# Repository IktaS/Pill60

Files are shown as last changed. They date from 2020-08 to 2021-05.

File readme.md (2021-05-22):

This is Pill 60, it offers various bottom row layout, a stepped caps, an OLED screen, and two rotary encoder, and uses Kailh Hotswap Socket, and underglow RGB LED.

layout is [this](http://www.keyboard-layout-editor.com/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)

This 60% keyboard that uses BluePill or STM32F103C8T6.This is my first board, Any feedback is appreciated. Contact me on Discord Ikta#8871.

## Firmware
Firmware is currently waiting for merge to QMK Firmware Repository, but you can still access it from my [fork](https://github.com/IktaS/qmk_firmware/tree/pill60/keyboards/handwired/pill60)

## Update
Modified the pinout diagram so that it doesn't crash with Black Pill or STM32F4xxx line of board, the pinout obviously will be different, but because all uses the a valid pin even with Black Pill / Blue Pill configuration, pin matrix diagram can be modified in firmware level.

## Caution
You might need to use a jumper for a more reliable connector in the caps/control key. I guess the pad is a bit too small for it to keep holding on with constant pressure of being pressed hard.

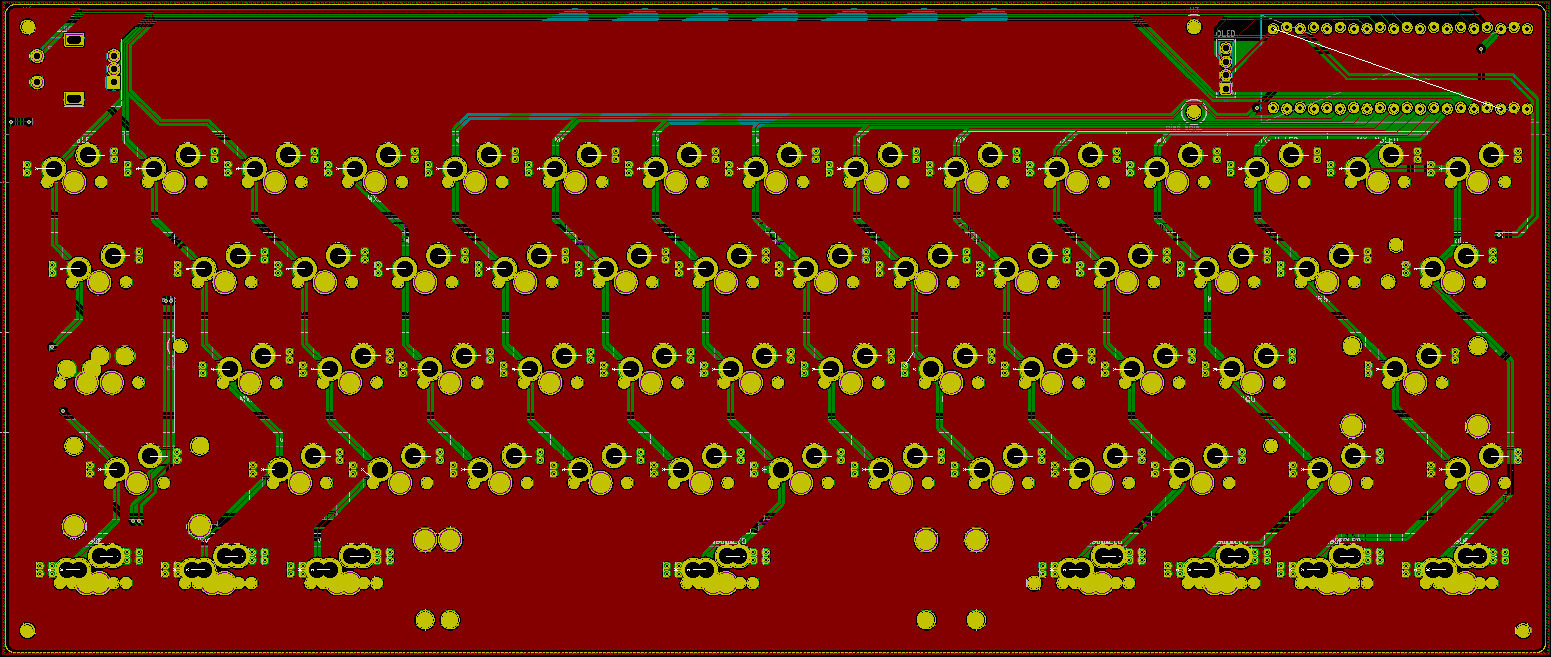
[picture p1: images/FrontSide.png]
Front Side view

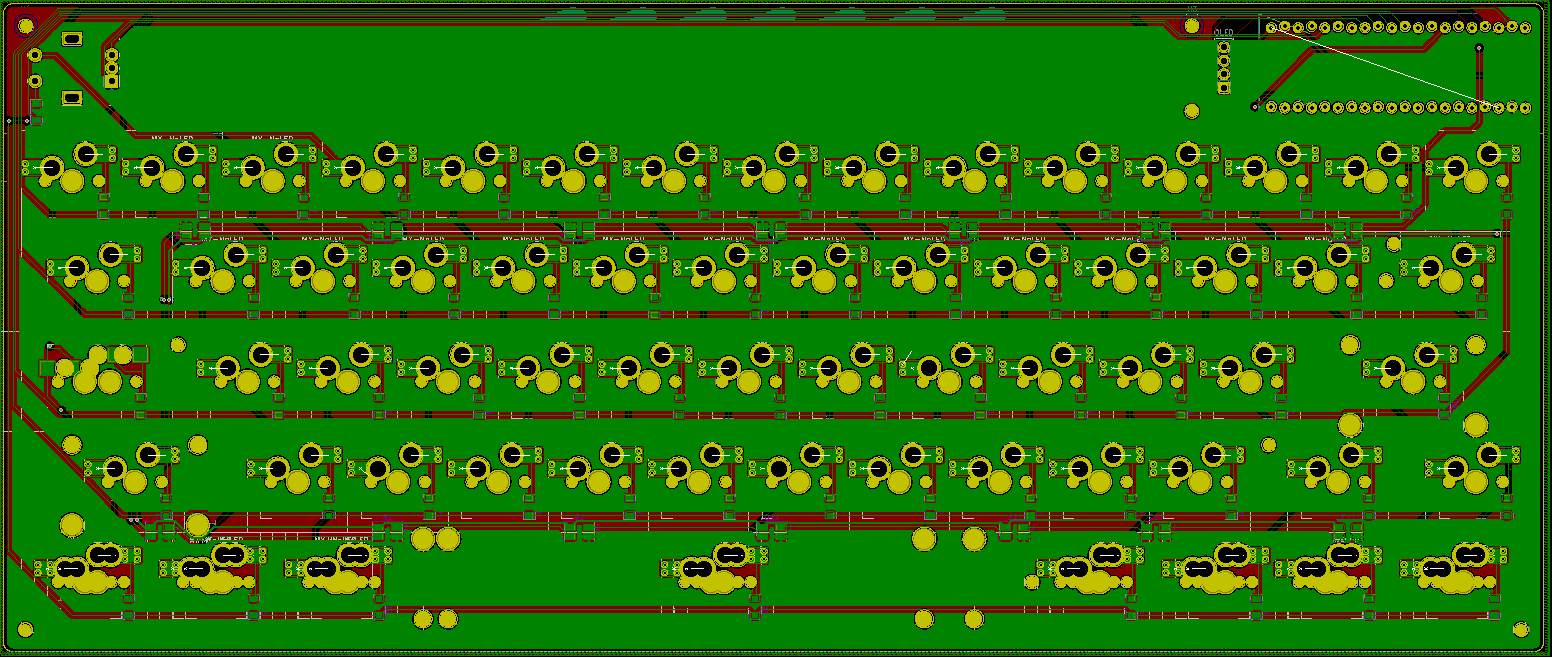
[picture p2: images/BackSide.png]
Back Side view

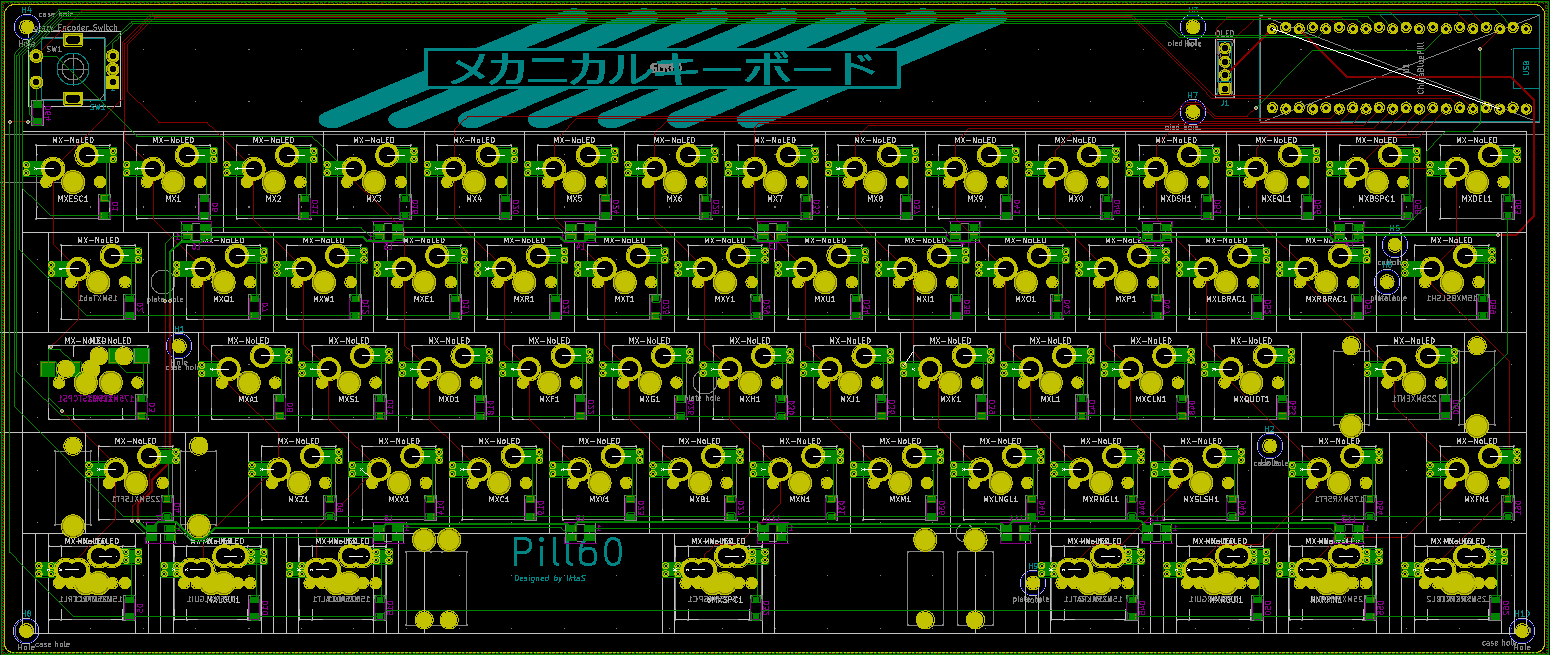
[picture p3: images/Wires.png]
Wire view

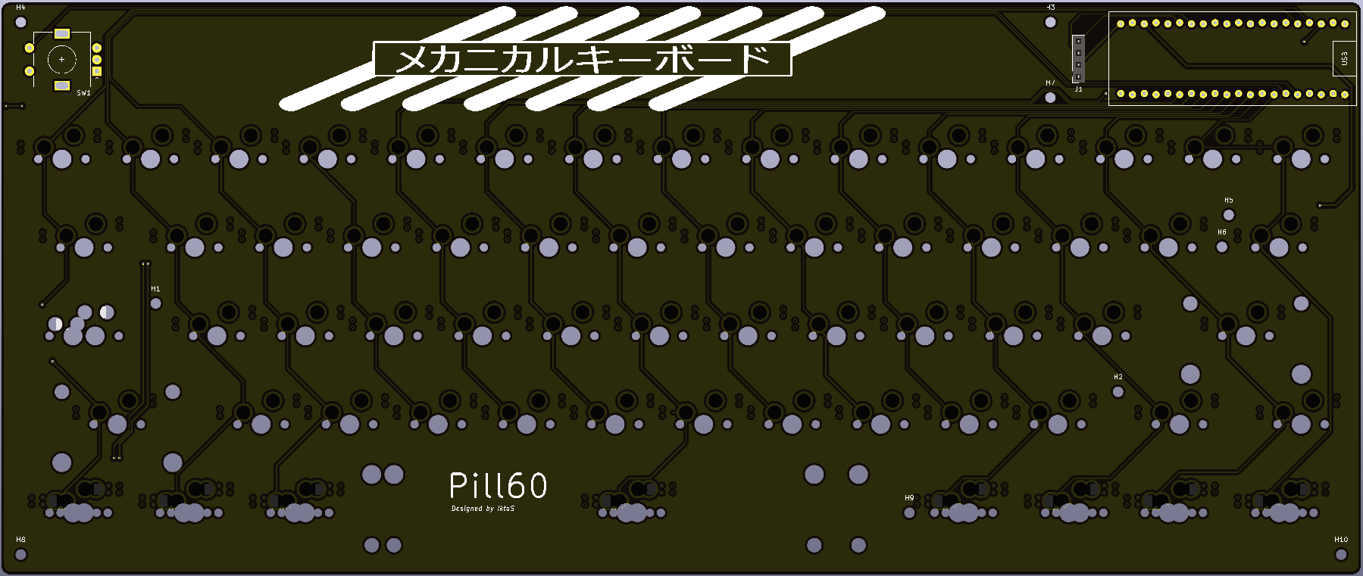
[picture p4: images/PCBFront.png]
PCB Front view

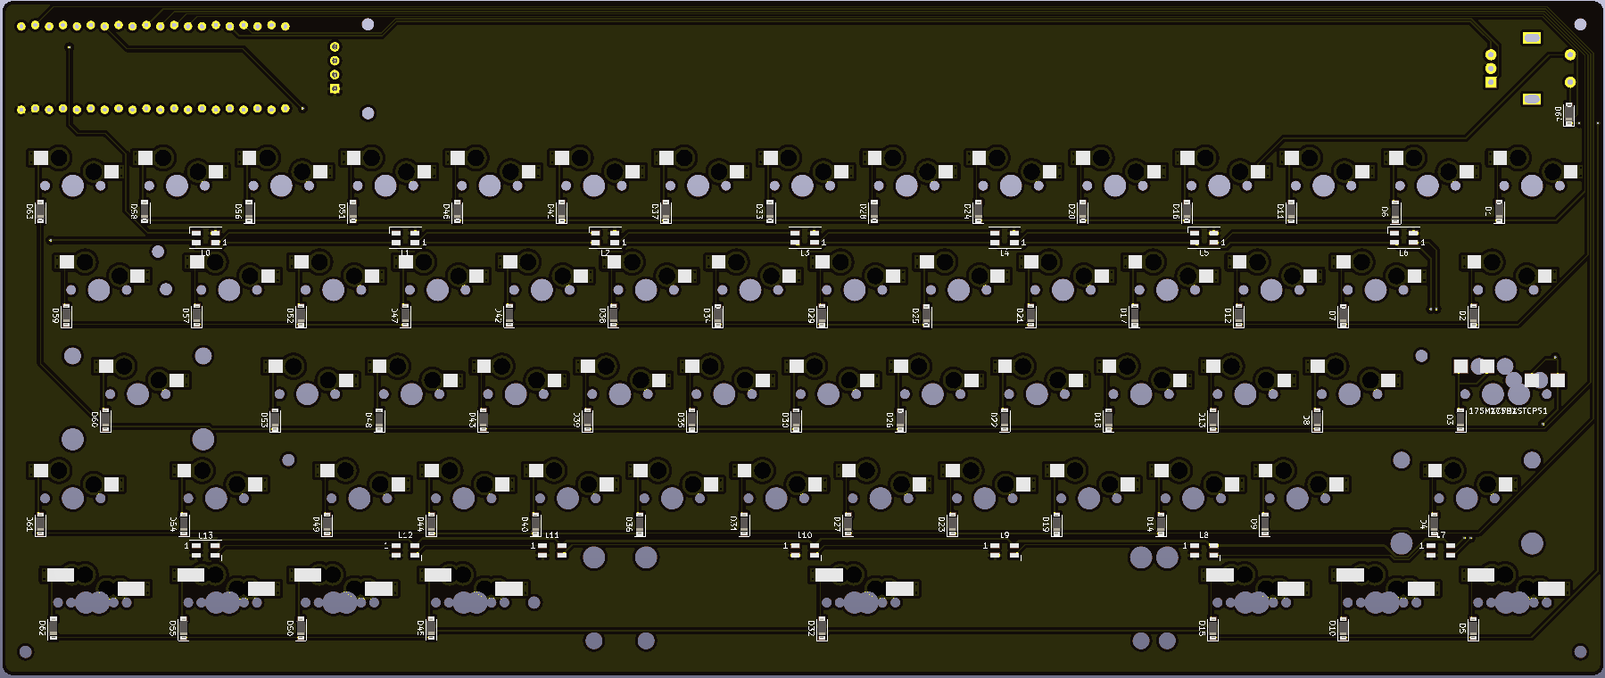
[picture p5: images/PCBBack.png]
PCB Back view


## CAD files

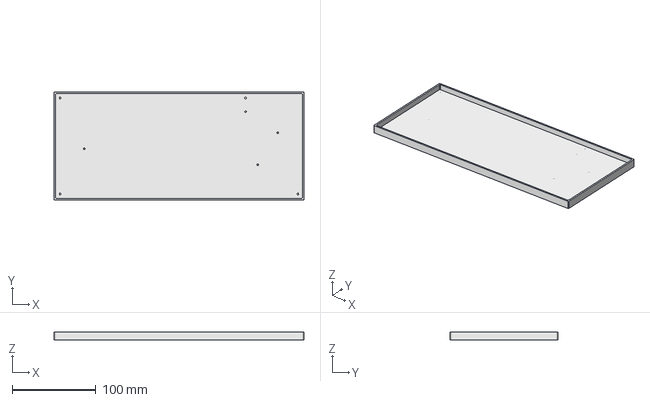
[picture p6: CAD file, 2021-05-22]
Case/CaseBase.FCStd
298.7 x 129.2 x 10.0 mm

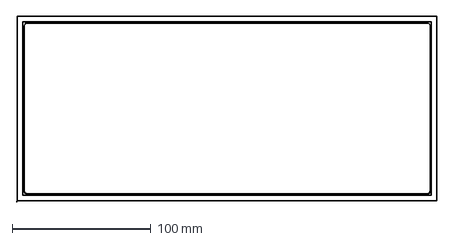
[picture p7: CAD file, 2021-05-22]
border.dxf
303.7 x 134.0 mm

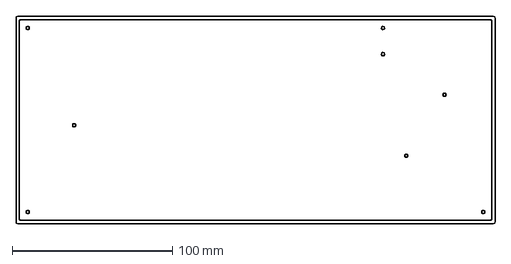
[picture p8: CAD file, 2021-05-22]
Case/CaseHoles.dxf
298.7 x 129.2 mm

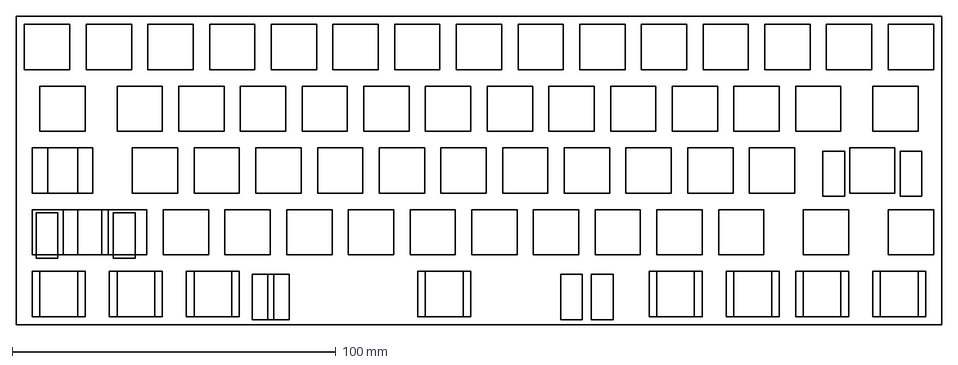
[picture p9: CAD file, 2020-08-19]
plate/ai03/ai03-plate-shortrshift.dxf
285.8 x 95.2 mm

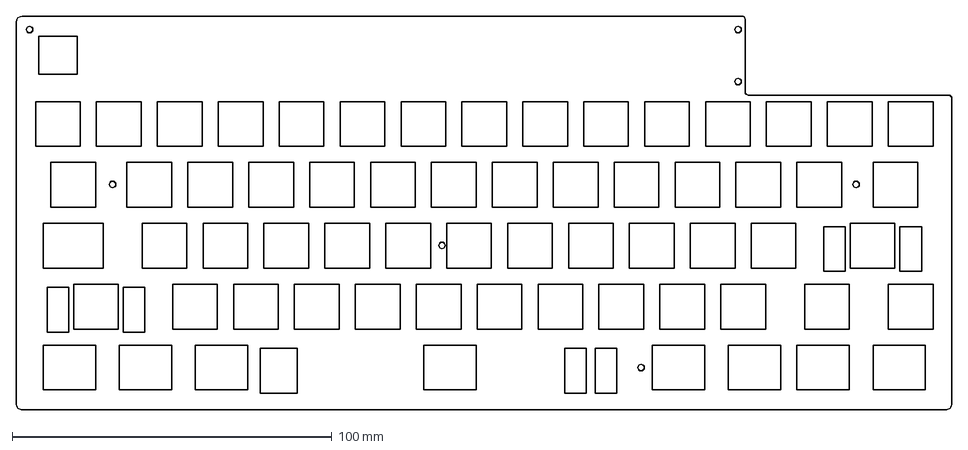
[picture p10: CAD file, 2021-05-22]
Case/PlateHoles.dxf
292.7 x 123.2 mm

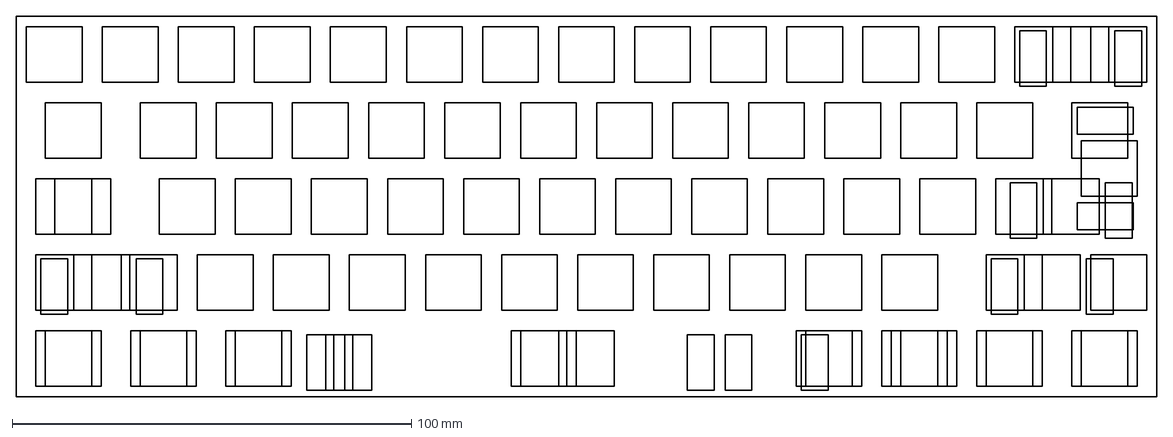
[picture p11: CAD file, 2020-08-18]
plate/ai03/ai03-plate.dxf
285.8 x 95.2 mm

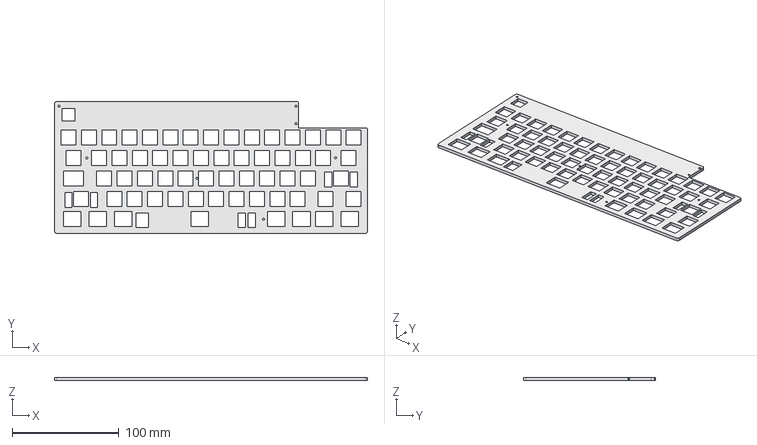
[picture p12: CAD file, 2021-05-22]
Case/PlateBase.FCStd
292.7 x 123.2 x 3.00 mm

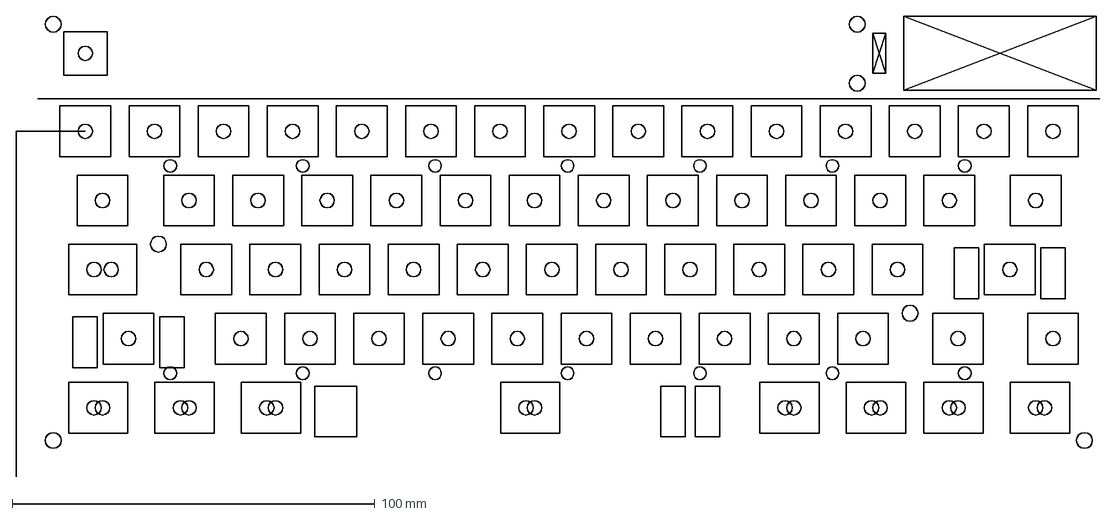
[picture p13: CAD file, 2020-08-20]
Switch Reference.dxf
298.7 x 127.0 mm

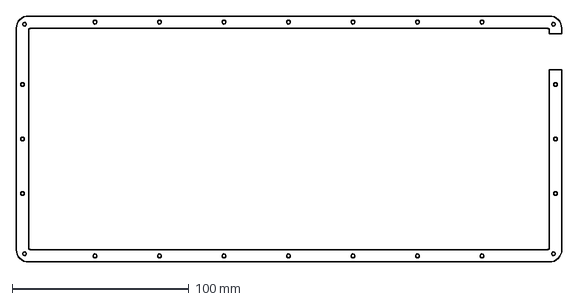
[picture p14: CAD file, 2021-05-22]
Case/CaseTopA-2mm.dxf
308.7 x 139.2 mm

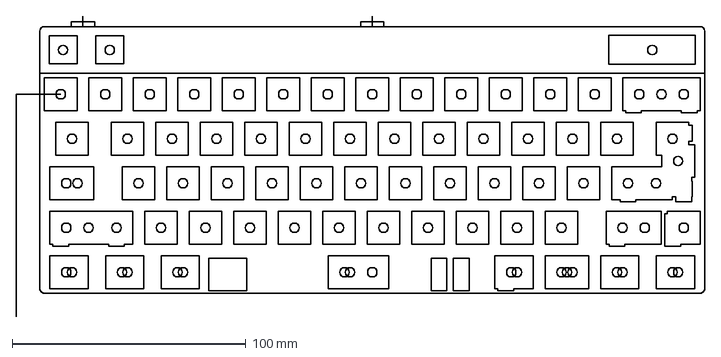
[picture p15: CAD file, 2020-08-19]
Reference-ai03.dxf
294.7 x 128.7 mm

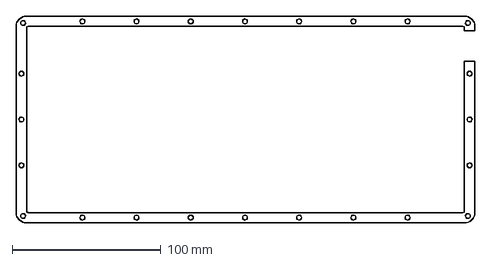
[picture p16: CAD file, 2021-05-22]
Case/CaseMiddle-8mm.dxf
308.7 x 139.2 mm

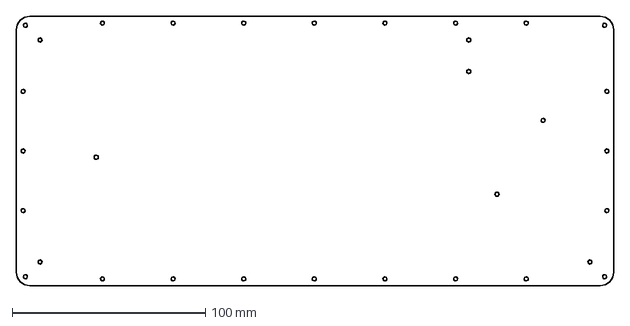
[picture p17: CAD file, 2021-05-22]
Case/CaseBottom-3mm.dxf
308.7 x 139.2 mm

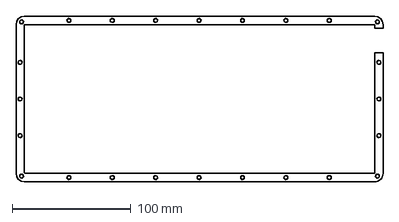
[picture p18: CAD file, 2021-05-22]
Case/CaseTopB-3mm.dxf
308.7 x 139.2 mm

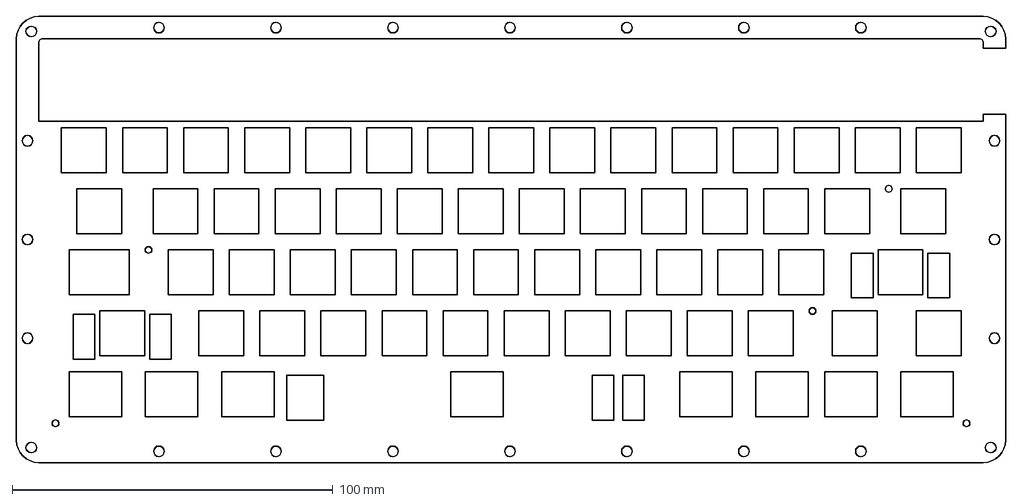
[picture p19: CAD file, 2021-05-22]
Case/CasePlate-2mm.dxf
308.7 x 139.2 mm

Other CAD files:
plate/ai03/plate-ai03.dxf
Switch-reference-left-Side.dxf
Switch Reference 2.dxf
Case/CasePlate-1,5mm.dxf
Case/CaseBase.dxf
Case/CaseBase.stl
Case/PlateBase.stl

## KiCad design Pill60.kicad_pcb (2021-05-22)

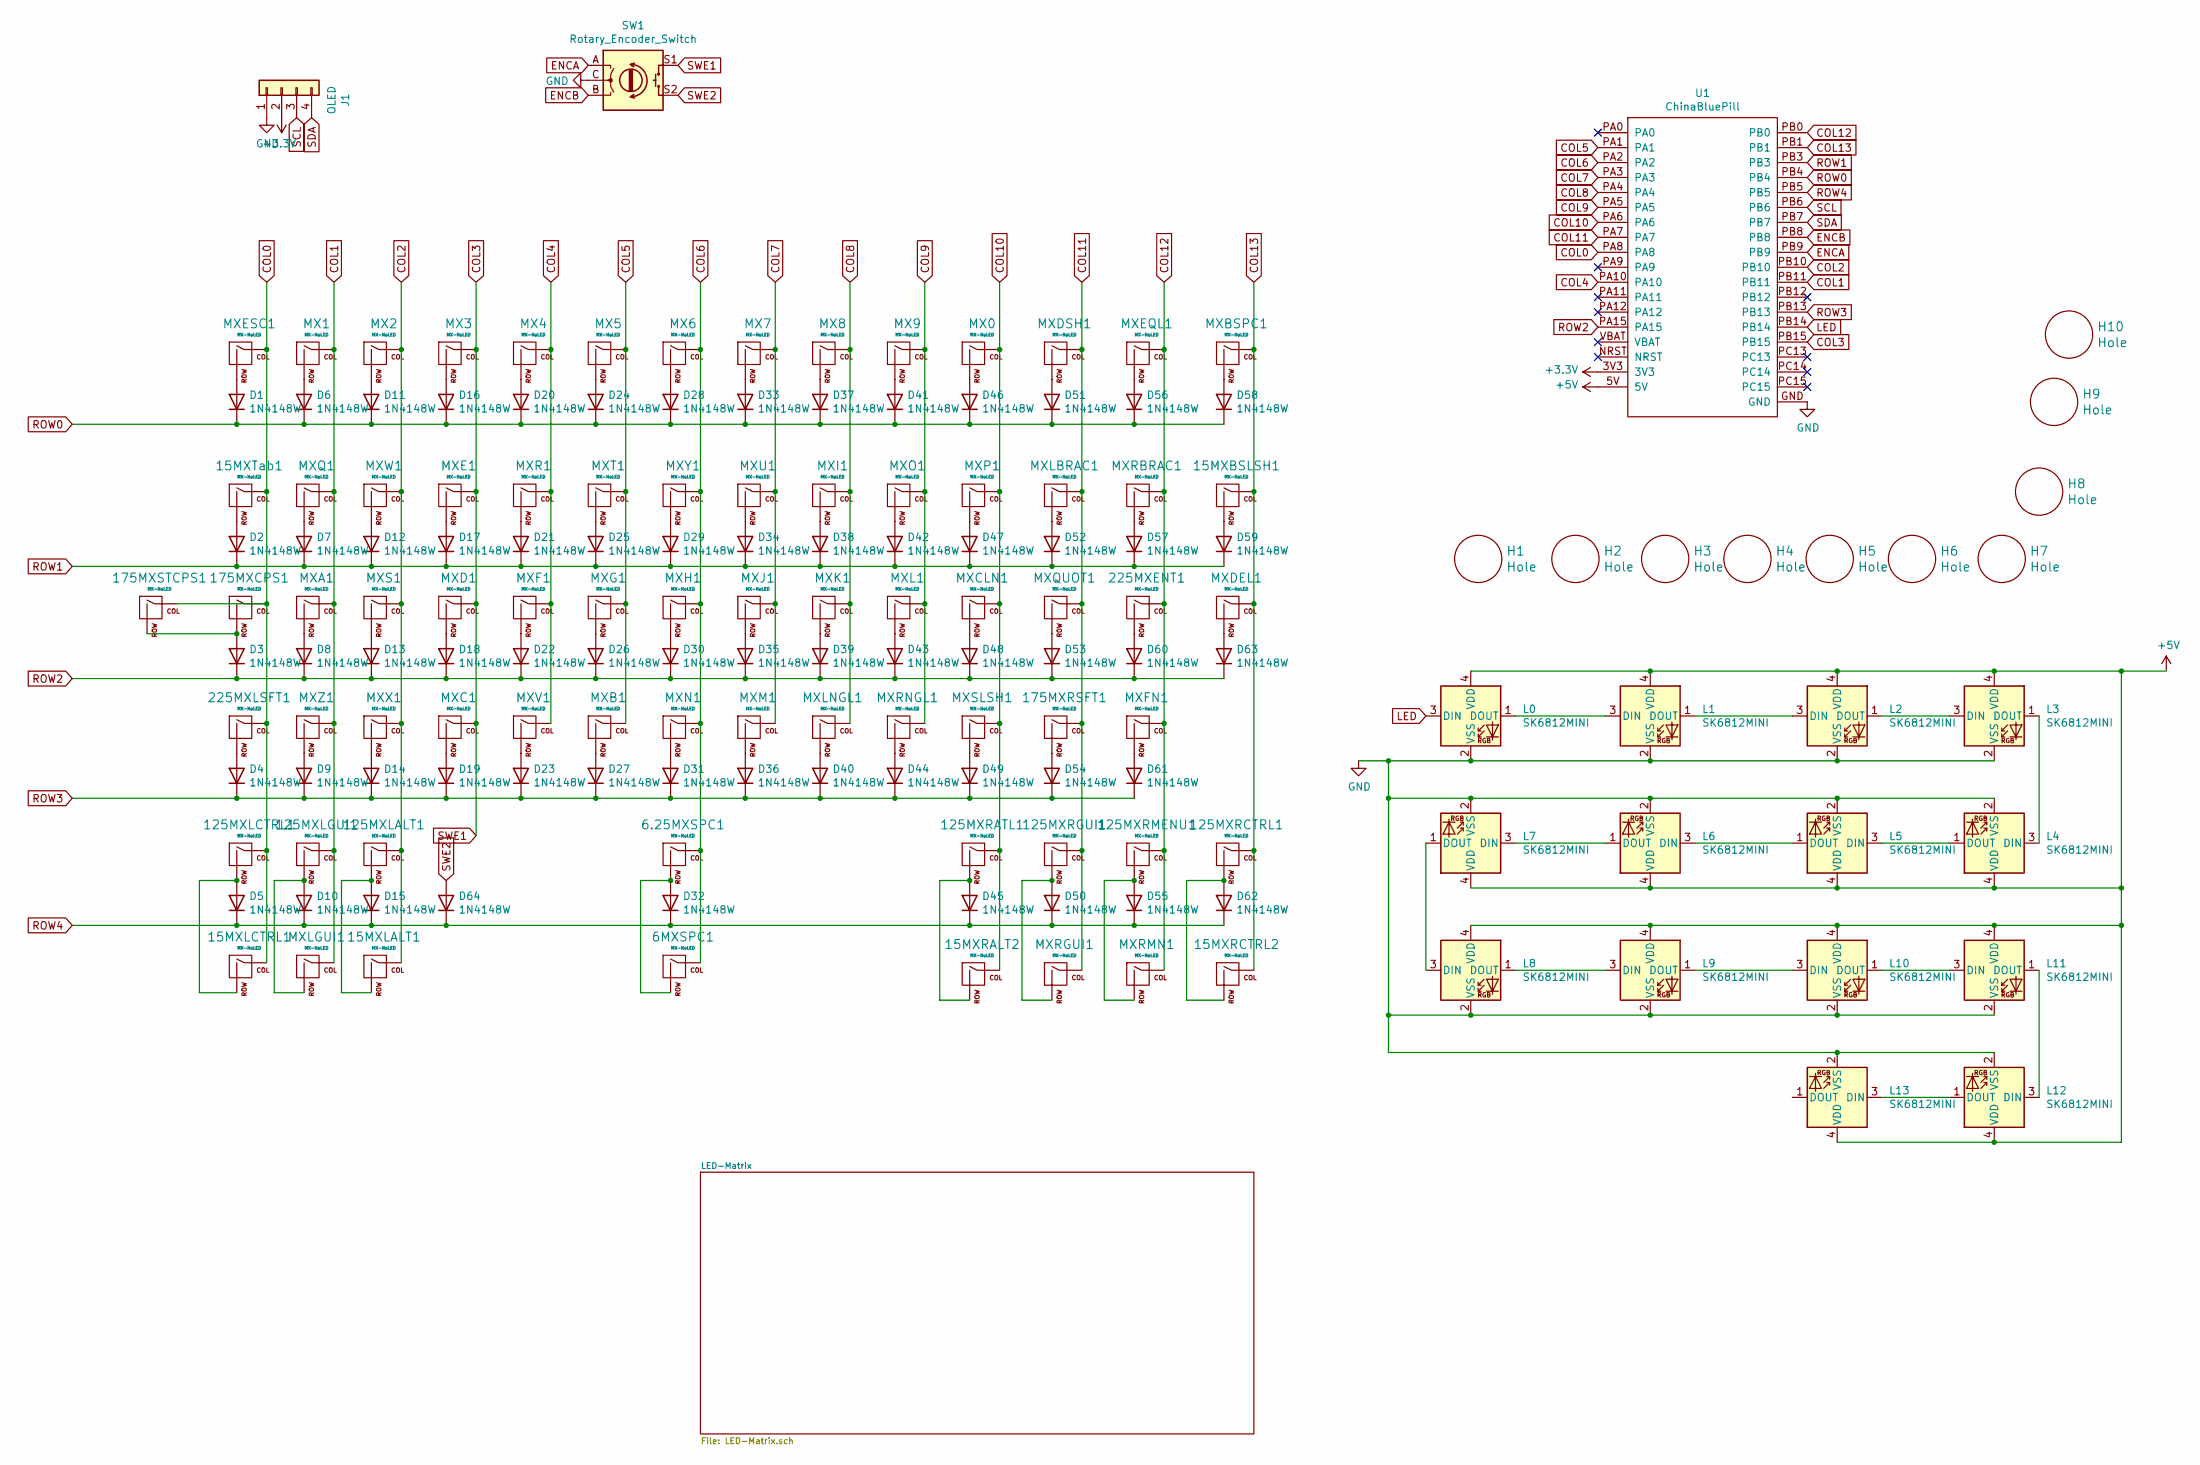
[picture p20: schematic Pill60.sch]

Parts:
6.25MXSPC1: MX-NoLED; MXOnly-6.25U-Hotswap-ReversedStabilizers-AntiShear
6MXSPC1: MX-NoLED; MXOnly-6U-ReversedStabilizers-NoLED-HotSwap-AntiShear
15MXBSLSH1, 15MXLALT1, 15MXLCTRL1, 15MXRALT2, 15MXRCTRL2, 15MXTab1: MX-NoLED; MXOnly-1.5U-Hotswap-AntiShear
125MXLALT1, 125MXLCTRL1, 125MXLGUI1, 125MXRATL1, 125MXRCTRL1, 125MXRGUI1, 125MXRMENU1: MX-NoLED; MXOnly-1.25U-Hotswap-AntiShear
175MXCPS1: MX-NoLED; MXOnly-1.75U-NoLED
175MXRSFT1: MX-NoLED; MXOnly-1.75U-Hotswap-AntiShear
175MXSTCPS1: MX-NoLED; MXOnly-1U-NoLED
225MXENT1, 225MXLSFT1: MX-NoLED; MXOnly-2.25U-Hotswap-AntiShear
D1, D2, D3, D4, D5, D6, D7, D8, D9, D10, D11, D12, D13, D14, D15, D16, D17, D18, D19, D20, D21, D22, D23, D24, D25, D26, D27, D28, D29, D30, D31, D32, D33, D34, D35, D36, D37, D38, D39, D40, D41, D42, D43, D44, D45, D46, D47, D48, D49, D50, D51, D52, D53, D54, D55, D56, D57, D58, D59, D60, D61, D62, D63, D64: 1N4148W; D_SOD-123
H1, H2, H3, H4, H5, H6, H7, H8, H9, H10: Hole; MountingHole_2.2mm_M2
J1: OLED; PinSocket_1x04_P2.54mm_Vertical
L0, L1, L2, L3, L4, L5, L6, L7, L8, L9, L10, L11, L12, L13: SK6812MINI; LED_SK6812MINI_PLCC4_3.5x3.5mm_P1.75mm
MX0, MX1, MX2, MX3, MX4, MX5, MX6, MX7, MX8, MX9: MX-NoLED; MXOnly-1U-Hotswap-Antishear
MXA1: MX-NoLED; MXOnly-1U-Hotswap-Antishear
MXB1: MX-NoLED; MXOnly-1U-Hotswap-Antishear
MXBSPC1: MX-NoLED; MXOnly-1U-Hotswap-Antishear
MXC1: MX-NoLED; MXOnly-1U-Hotswap-Antishear
MXCLN1: MX-NoLED; MXOnly-1U-Hotswap-Antishear
MXD1: MX-NoLED; MXOnly-1U-Hotswap-Antishear
MXDEL1: MX-NoLED; MXOnly-1U-Hotswap-Antishear
MXDSH1: MX-NoLED; MXOnly-1U-Hotswap-Antishear
MXE1: MX-NoLED; MXOnly-1U-Hotswap-Antishear
MXEQL1: MX-NoLED; MXOnly-1U-Hotswap-Antishear
MXESC1: MX-NoLED; MXOnly-1U-Hotswap-Antishear
MXF1: MX-NoLED; MXOnly-1U-Hotswap-Antishear
MXFN1: MX-NoLED; MXOnly-1U-Hotswap-Antishear
MXG1: MX-NoLED; MXOnly-1U-Hotswap-Antishear
MXH1: MX-NoLED; MXOnly-1U-Hotswap-Antishear
MXI1: MX-NoLED; MXOnly-1U-Hotswap-Antishear
MXJ1: MX-NoLED; MXOnly-1U-Hotswap-Antishear
MXK1: MX-NoLED; MXOnly-1U-Hotswap-Antishear
MXL1: MX-NoLED; MXOnly-1U-Hotswap-Antishear
MXLBRAC1: MX-NoLED; MXOnly-1U-Hotswap-Antishear
MXLGUI1: MX-NoLED; MXOnly-1U-Hotswap-Antishear
MXLNGL1: MX-NoLED; MXOnly-1U-Hotswap-Antishear
MXM1: MX-NoLED; MXOnly-1U-Hotswap-Antishear
MXN1: MX-NoLED; MXOnly-1U-Hotswap-Antishear
MXO1: MX-NoLED; MXOnly-1U-Hotswap-Antishear
MXP1: MX-NoLED; MXOnly-1U-Hotswap-Antishear
MXQ1: MX-NoLED; MXOnly-1U-Hotswap-Antishear
MXQUOT1: MX-NoLED; MXOnly-1U-Hotswap-Antishear
MXR1: MX-NoLED; MXOnly-1U-Hotswap-Antishear
MXRBRAC1: MX-NoLED; MXOnly-1U-Hotswap-Antishear
MXRGUI1: MX-NoLED; MXOnly-1U-Hotswap-Antishear
MXRMN1: MX-NoLED; MXOnly-1U-Hotswap-Antishear
MXRNGL1: MX-NoLED; MXOnly-1U-Hotswap-Antishear
MXS1: MX-NoLED; MXOnly-1U-Hotswap-Antishear
MXSLSH1: MX-NoLED; MXOnly-1U-Hotswap-Antishear
MXT1: MX-NoLED; MXOnly-1U-Hotswap-Antishear
MXU1: MX-NoLED; MXOnly-1U-Hotswap-Antishear
MXV1: MX-NoLED; MXOnly-1U-Hotswap-Antishear
MXW1: MX-NoLED; MXOnly-1U-Hotswap-Antishear
MXX1: MX-NoLED; MXOnly-1U-Hotswap-Antishear
MXY1: MX-NoLED; MXOnly-1U-Hotswap-Antishear
MXZ1: MX-NoLED; MXOnly-1U-Hotswap-Antishear
SW1: Rotary_Encoder_Switch; RotaryEncoder_Alps_EC11E-Switch_Vertical_H20mm
U1: ChinaBluePill; ChinaBluePill_SneakyFootprint

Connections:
+3V3: J1.2, U1.3V3
+5V: L0.4 (VDD), L1.4 (VDD), L2.4 (VDD), L3.4 (VDD), L4.4 (VDD), L5.4 (VDD), L6.4 (VDD), L7.4 (VDD), L8.4 (VDD), L9.4 (VDD), L10.4 (VDD), L11.4 (VDD), L12.4 (VDD), L13.4 (VDD), U1.5V
COL0: 15MXLCTRL1.1 (COL), 15MXTab1.1 (COL), 125MXLCTRL1.1 (COL), 175MXCPS1.1 (COL), 175MXSTCPS1.1 (COL), 225MXLSFT1.1 (COL), MXESC1.1 (COL), U1.PA8
COL1: 125MXLGUI1.1 (COL), MX1.1 (COL), MXA1.1 (COL), MXLGUI1.1 (COL), MXQ1.1 (COL), MXZ1.1 (COL), U1.PB11
COL2: 15MXLALT1.1 (COL), 125MXLALT1.1 (COL), MX2.1 (COL), MXS1.1 (COL), MXW1.1 (COL), MXX1.1 (COL), U1.PB10
COL3: MX3.1 (COL), MXC1.1 (COL), MXD1.1 (COL), MXE1.1 (COL), SW1.S1, U1.PB15
COL4: MX4.1 (COL), MXF1.1 (COL), MXR1.1 (COL), MXV1.1 (COL), U1.PA10
COL5: MX5.1 (COL), MXB1.1 (COL), MXG1.1 (COL), MXT1.1 (COL), U1.PA1
COL6: 6.25MXSPC1.1 (COL), 6MXSPC1.1 (COL), MX6.1 (COL), MXH1.1 (COL), MXN1.1 (COL), MXY1.1 (COL), U1.PA2
COL7: MX7.1 (COL), MXJ1.1 (COL), MXM1.1 (COL), MXU1.1 (COL), U1.PA3
COL8: MX8.1 (COL), MXI1.1 (COL), MXK1.1 (COL), MXLNGL1.1 (COL), U1.PA4
COL9: MX9.1 (COL), MXL1.1 (COL), MXO1.1 (COL), MXRNGL1.1 (COL), U1.PA5
COL10: 15MXRALT2.1 (COL), 125MXRATL1.1 (COL), MX0.1 (COL), MXCLN1.1 (COL), MXP1.1 (COL), MXSLSH1.1 (COL), U1.PA6
COL11: 125MXRGUI1.1 (COL), 175MXRSFT1.1 (COL), MXDSH1.1 (COL), MXLBRAC1.1 (COL), MXQUOT1.1 (COL), MXRGUI1.1 (COL), U1.PA7
COL12: 125MXRMENU1.1 (COL), 225MXENT1.1 (COL), MXEQL1.1 (COL), MXFN1.1 (COL), MXRBRAC1.1 (COL), MXRMN1.1 (COL), U1.PB0
COL13: 15MXBSLSH1.1 (COL), 15MXRCTRL2.1 (COL), 125MXRCTRL1.1 (COL), MXBSPC1.1 (COL), MXDEL1.1 (COL), U1.PB1
ENCA: SW1.A, U1.PB9
ENCB: SW1.B, U1.PB8
GND: J1.1, L0.2 (VSS), L1.2 (VSS), L2.2 (VSS), L3.2 (VSS), L4.2 (VSS), L5.2 (VSS), L6.2 (VSS), L7.2 (VSS), L8.2 (VSS), L9.2 (VSS), L10.2 (VSS), L11.2 (VSS), L12.2 (VSS), L13.2 (VSS), SW1.C, U1.GND
LED: L0.3 (DIN), U1.PB14
unnamed: 6.25MXSPC1.2 (ROW), 6MXSPC1.2 (ROW), D32.2 (A)
unnamed: 15MXBSLSH1.2 (ROW), D59.2 (A)
unnamed: 15MXTab1.2 (ROW), D2.2 (A)
unnamed: 15MXLALT1.2 (ROW), 125MXLALT1.2 (ROW), D15.2 (A)
unnamed: 15MXLCTRL1.2 (ROW), 125MXLCTRL1.2 (ROW), D5.2 (A)
unnamed: 125MXLGUI1.2 (ROW), D10.2 (A), MXLGUI1.2 (ROW)
unnamed: 15MXRALT2.2 (ROW), 125MXRATL1.2 (ROW), D45.2 (A)
unnamed: 15MXRCTRL2.2 (ROW), 125MXRCTRL1.2 (ROW), D62.2 (A)
unnamed: 125MXRGUI1.2 (ROW), D50.2 (A), MXRGUI1.2 (ROW)
unnamed: 125MXRMENU1.2 (ROW), D55.2 (A), MXRMN1.2 (ROW)
unnamed: 175MXCPS1.2 (ROW), 175MXSTCPS1.2 (ROW), D3.2 (A)
unnamed: 175MXRSFT1.2 (ROW), D54.2 (A)
unnamed: 225MXENT1.2 (ROW), D60.2 (A)
unnamed: 225MXLSFT1.2 (ROW), D4.2 (A)
unnamed: D1.2 (A), MXESC1.2 (ROW)
unnamed: D6.2 (A), MX1.2 (ROW)
unnamed: D7.2 (A), MXQ1.2 (ROW)
unnamed: D8.2 (A), MXA1.2 (ROW)
unnamed: D9.2 (A), MXZ1.2 (ROW)
unnamed: D11.2 (A), MX2.2 (ROW)
unnamed: D12.2 (A), MXW1.2 (ROW)
unnamed: D13.2 (A), MXS1.2 (ROW)
unnamed: D14.2 (A), MXX1.2 (ROW)
unnamed: D16.2 (A), MX3.2 (ROW)
unnamed: D17.2 (A), MXE1.2 (ROW)
unnamed: D18.2 (A), MXD1.2 (ROW)
unnamed: D19.2 (A), MXC1.2 (ROW)
unnamed: D20.2 (A), MX4.2 (ROW)
unnamed: D21.2 (A), MXR1.2 (ROW)
unnamed: D22.2 (A), MXF1.2 (ROW)
unnamed: D23.2 (A), MXV1.2 (ROW)
unnamed: D24.2 (A), MX5.2 (ROW)
unnamed: D25.2 (A), MXT1.2 (ROW)
unnamed: D26.2 (A), MXG1.2 (ROW)
unnamed: D27.2 (A), MXB1.2 (ROW)
unnamed: D28.2 (A), MX6.2 (ROW)
unnamed: D29.2 (A), MXY1.2 (ROW)
unnamed: D30.2 (A), MXH1.2 (ROW)
unnamed: D31.2 (A), MXN1.2 (ROW)
unnamed: D33.2 (A), MX7.2 (ROW)
unnamed: D34.2 (A), MXU1.2 (ROW)
unnamed: D35.2 (A), MXJ1.2 (ROW)
unnamed: D36.2 (A), MXM1.2 (ROW)
unnamed: D37.2 (A), MX8.2 (ROW)
unnamed: D38.2 (A), MXI1.2 (ROW)
unnamed: D39.2 (A), MXK1.2 (ROW)
unnamed: D40.2 (A), MXLNGL1.2 (ROW)
unnamed: D41.2 (A), MX9.2 (ROW)
unnamed: D42.2 (A), MXO1.2 (ROW)
unnamed: D43.2 (A), MXL1.2 (ROW)
unnamed: D44.2 (A), MXRNGL1.2 (ROW)
unnamed: D46.2 (A), MX0.2 (ROW)
unnamed: D47.2 (A), MXP1.2 (ROW)
unnamed: D48.2 (A), MXCLN1.2 (ROW)
unnamed: D49.2 (A), MXSLSH1.2 (ROW)
unnamed: D51.2 (A), MXDSH1.2 (ROW)
unnamed: D52.2 (A), MXLBRAC1.2 (ROW)
unnamed: D53.2 (A), MXQUOT1.2 (ROW)
unnamed: D56.2 (A), MXEQL1.2 (ROW)
unnamed: D57.2 (A), MXRBRAC1.2 (ROW)
unnamed: D58.2 (A), MXBSPC1.2 (ROW)
unnamed: D61.2 (A), MXFN1.2 (ROW)
unnamed: D63.2 (A), MXDEL1.2 (ROW)
unnamed: L0.1 (DOUT), L1.3 (DIN)
unnamed: L1.1 (DOUT), L2.3 (DIN)
unnamed: L2.1 (DOUT), L3.3 (DIN)
unnamed: L3.1 (DOUT), L4.3 (DIN)
unnamed: L4.1 (DOUT), L5.3 (DIN)
unnamed: L5.1 (DOUT), L6.3 (DIN)
unnamed: L6.1 (DOUT), L7.3 (DIN)
unnamed: L7.1 (DOUT), L8.3 (DIN)
unnamed: L8.1 (DOUT), L9.3 (DIN)
unnamed: L10.1 (DOUT), L11.3 (DIN)
unnamed: L9.1 (DOUT), L10.3 (DIN)
unnamed: L11.1 (DOUT), L12.3 (DIN)
unnamed: L12.1 (DOUT), L13.3 (DIN)
ROW0: D1.1 (K), D6.1 (K), D11.1 (K), D16.1 (K), D20.1 (K), D24.1 (K), D28.1 (K), D33.1 (K), D37.1 (K), D41.1 (K), D46.1 (K), D51.1 (K), D56.1 (K), D58.1 (K), U1.PB4
ROW1: D2.1 (K), D7.1 (K), D12.1 (K), D17.1 (K), D21.1 (K), D25.1 (K), D29.1 (K), D34.1 (K), D38.1 (K), D42.1 (K), D47.1 (K), D52.1 (K), D57.1 (K), D59.1 (K), U1.PB3
ROW2: D3.1 (K), D8.1 (K), D13.1 (K), D18.1 (K), D22.1 (K), D26.1 (K), D30.1 (K), D35.1 (K), D39.1 (K), D43.1 (K), D48.1 (K), D53.1 (K), D60.1 (K), D63.1 (K), U1.PA15
ROW3: D4.1 (K), D9.1 (K), D14.1 (K), D19.1 (K), D23.1 (K), D27.1 (K), D31.1 (K), D36.1 (K), D40.1 (K), D44.1 (K), D49.1 (K), D54.1 (K), D61.1 (K), U1.PB13
ROW4: D5.1 (K), D10.1 (K), D15.1 (K), D32.1 (K), D45.1 (K), D50.1 (K), D55.1 (K), D62.1 (K), D64.1 (K), U1.PB5
SCL: J1.3, U1.PB6
SDA: J1.4, U1.PB7
SWE2: D64.2 (A), SW1.S2

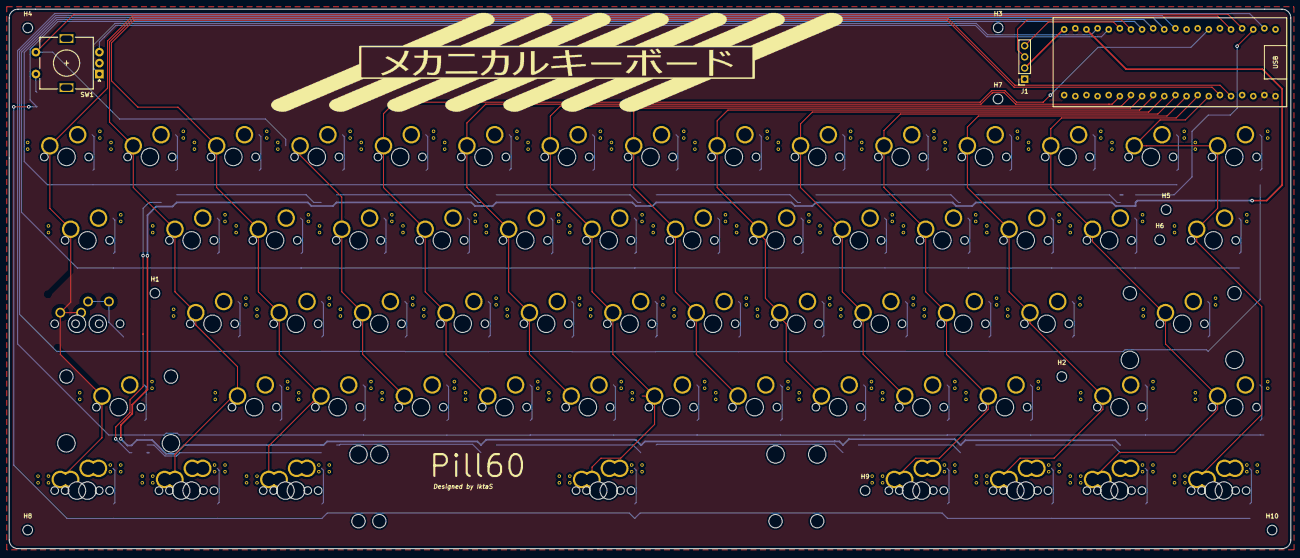
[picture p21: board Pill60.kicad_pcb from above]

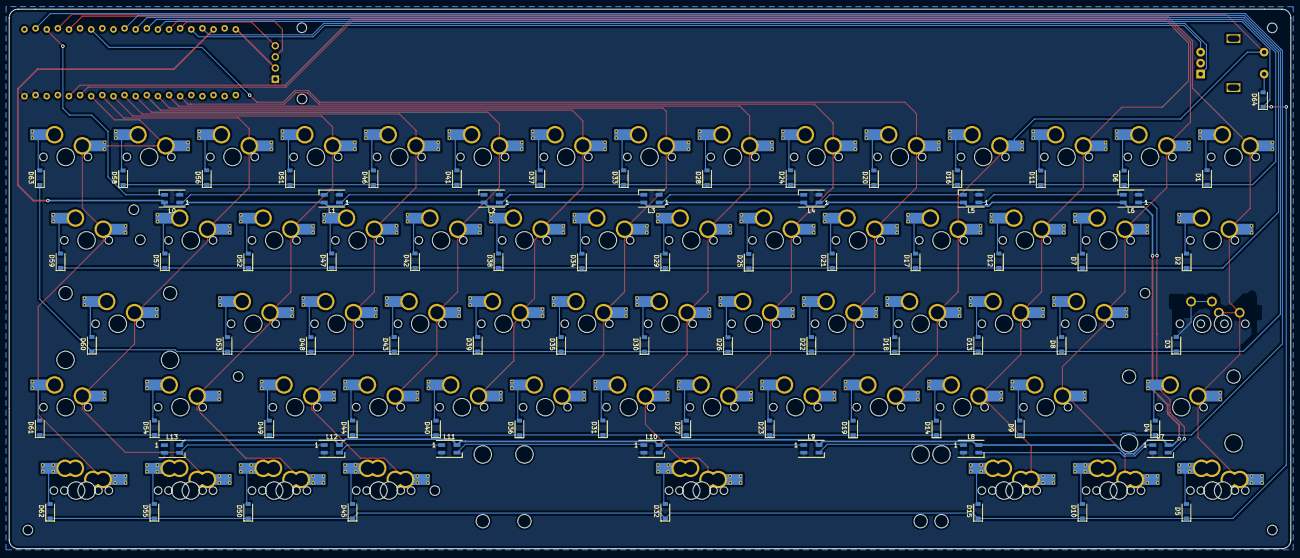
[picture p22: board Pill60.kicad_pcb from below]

Board: 2 copper layers, 292.7 x 123.2 mm, 163 parts (78 on the bottom side), 104 nets.

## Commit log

2020-08-18 reference southwest mat
    [Reference.dxf, ai03-plate.dxf, swillkb-plate.dxf]
2020-08-18 reference ai03 done
    [Reference-ai03.dxf, ai03-plate.dxf]
2020-08-19 add lib
    [Varity60.kicad_pcb, Varity60.sch]
2020-08-19 hard pivot
    [Reference.dxf, Switch Reference.dxf, Varity60.kicad_pcb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]
2020-08-19 pivot MCU
    [Varity60.kicad_pcb, Varity60.sch]
2020-08-20 done wiring etc
    [#plate-swillkb.dxf, Switch Reference.dxf, Varity60.kicad_pcb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]
2020-08-20 images and readme
    [Pill60.kicad_pcb]
2020-08-20 add underglow
    [#plate-swillkb.dxf, Pill60.kicad_pcb, Pill60.sch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]
2020-08-20 fix stupid mistakes
    [Pill60-B_Cu.gbr, Pill60-B_Mask.gbr, Pill60-B_Paste.gbr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]
2020-08-21 connecting some grounds
    [Pill60.kicad_pcb]
2020-08-21 Fix wires and make stuff better
    [Pill60.kicad_pcb, Pill60.sch]
2020-08-21 Gerbers v1.1.1
    [Pill60-B_Cu.gbr, Pill60-B_Mask.gbr, Pill60-B_Paste.gbr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]
2020-08-21 readme and images
    [Pill60.kicad_pcb]
2020-08-21 Better wires
    [Pill60-B_Cu.gbr, Pill60-B_Mask.gbr, Pill60-B_Paste.gbr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]
2020-08-21 fixed stupid mistake
    [Pill60-B_Cu.gbr, Pill60-B_Mask.gbr, Pill60-B_Paste.gbr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]
2020-08-21 added more holes for plate and pcb mounting
    [Pill60-B_Cu.gbr, Pill60-B_Mask.gbr, Pill60-B_Paste.gbr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]
2020-08-22 Gerber for latest version
    [Pill60-B_Cu.gbr, Pill60-B_Mask.gbr, Pill60-B_Paste.gbr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]
2020-08-22 readme and images update
    [Pill60.kicad_pcb]
2020-08-22 Sneaky footprint
    offset pin holes for bluepill, might or might not work
    [Pill60.kicad_pcb, Pill60.sch]
2020-08-22 images and gerber
    [Pill60-B_Cu.gbr, Pill60-B_Mask.gbr, Pill60-B_Paste.gbr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]
2020-08-22 added support for blackpill
    [Pill60.kicad_pcb, Pill60.sch]
2020-08-24 changed pin diagram to avoid bad pin
    [Pill60.kicad_pcb, Pill60.sch]
2020-08-24 Images and gerbers
    [Pill60-B_Cu.gbr, Pill60-B_Mask.gbr, Pill60-B_Paste.gbr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]
2020-08-29 create reference in plate file
    [LED-Matrix.sch, Pill60.sch, plate-ai03.dxf]
2020-10-30 update readme and add case files
    [CaseBase.FCStd, CaseBase.stl, CaseHoles.dxf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]
2021-05-22 add acrylic case files
    [CaseBase.dxf, CaseBottom-3mm.dxf, CaseMiddle-8mm.dxf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]
